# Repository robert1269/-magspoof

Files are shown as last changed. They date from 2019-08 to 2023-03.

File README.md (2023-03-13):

# MagSpoof V3 - Credit Card/Magstripe Spoofer

<a href="https://electroniccats.com/producto/magspoof-v3/">
  <p align="center">
  
  </p>
</a>

# How does MagSpoof work?

**MagSpoof V3** is a device that can spoof/emulate any magnetic stripe or credit card. It can work "wirelessly", even on **standard magstripe/credit card readers**, by generating a strong electromagnetic field that emulates a traditional magnetic stripe card.

* Allows you to store all of your credit cards and magstripes in one device
* Works on traditional magstripe readers **wirelessly** (no NFC/RFID required)
* Can **disable** Chip-and-PIN (code not included)
* Correctly **predicts** Amex credit card numbers + expirations from previous card number (code not included)
* Supports all three magnetic stripe tracks, and even supports Track 1+2 simultaneously
* Easy to build using Arduino or other common parts

MagSpoof can be used as a traditional credit card and simply store all of your credit cards (and with modification, can technically disable chip requirements) in various impressive and exciting form factors, or can be used for security research in any area that would traditionally require a magstripe, such as readers for credit cards, drivers licenses, hotel room keys, automated parking lot tickets, etc.

**Note:** MagSpoof does **not** enable you to use credit cards that you are not legally authorized to use. The Chip-and-PIN and Amex information is **not** implemented and using MagSpoof requires you to have/own the magstripes that you wish to emulate. Simply having a credit card number and expiration is not enough to perform transactions. MagSpoof **does** allow you to perform research in other areas of magstripes, microcontrollers, and electromagnetism, as well as learn about and create your own devices similar to other existing, commercial technologies such as <a href="http://www.samsung.com/us/support/answer/ANS00043865/997410383/">Samsung MST</a> and <a href="https://onlycoin.com/">Coin</a>.</p>

-----

# Based in work of Samy Kamkar

**Point of Contact:** [@SamyKamkar](https://twitter.com/samykamkar)

You can see more of my projects at <http://samy.pl> or contact me at <code@samy.pl>.

------

# Wiki and Getting Started 
**[Getting Started in our Wiki](https://github.com/ElectronicCats/magspoof/wiki)**

<p align="center">
  
</p>

------
# License
<a>
  
</a>
Electronic Cats invests time and resources in providing this open-source design. Please support Electronic Cats and open-source hardware by purchasing products from Electronic Cats!

Designed by Electronic Cats.

Firmware released under an GNU AGPL v3.0 license. See the LICENSE file for more information.

Hardware released under an CERN Open Hardware Licence v1.2. See the LICENSE_HARDWARE file for more information.

Electronic Cats is a registered trademark, please do not use if you sell these PCBs.

30 Octuber 2019

------

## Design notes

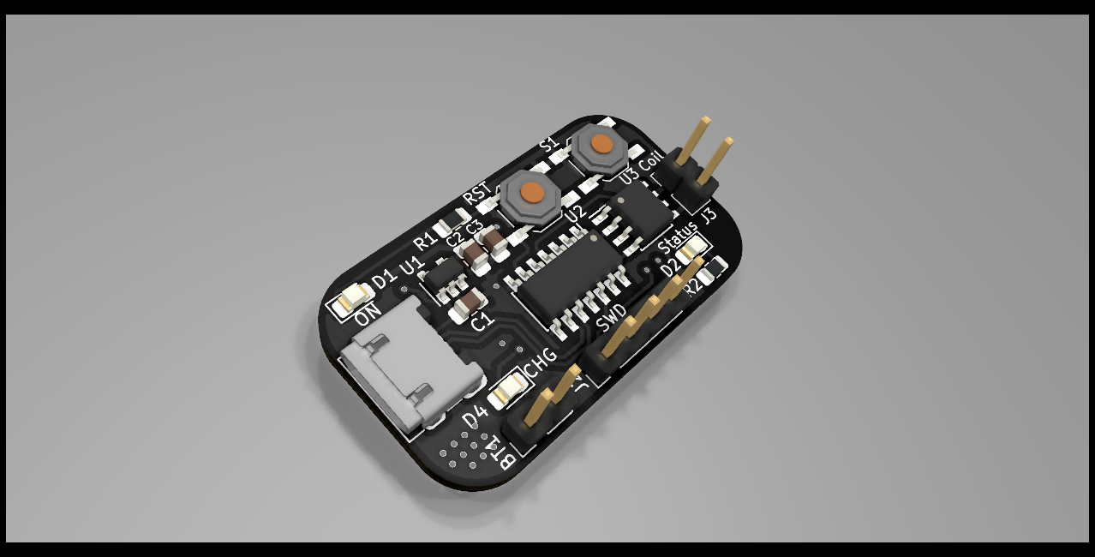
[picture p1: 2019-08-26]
V3/Hw/Magspoof_V3.png

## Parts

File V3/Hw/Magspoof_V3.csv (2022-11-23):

Item | Qty | Reference(s) | Value | manf#
1 | 1 | BT1 | Battery_Cell | -
2 | 4 | C1, C2, C4, C5 | 10uF | CL21A106KOQNNNG
3 | 1 | C3 | 0.1uF | CL21F104ZBCNNNC
4 | 1 | D1 | ON | 150080RS75000
5 | 1 | D2 | Status | 150080BS75000
6 | 1 | D3 | MBR120 | MBR120VLSFT3G
7 | 1 | D4 | CHG | 150080GS75000
8 | 1 | J1 | USB_B_Micro | 629105150521
9 | 1 | J2 | SWD | -
10 | 1 | J3 | Coil | -
11 | 2 | R1, R2 | 180R | RMCF0805JT180R
12 | 1 | R3 | 4.7K | RS-05K472JT
13 | 1 | R4 | 470 | CRCW0805470RFKEAC
14 | 1 | SW1 | RST | -
15 | 1 | SW2 | S1 | -
16 | 1 | U1 | AP2112K-3.3 | AP2112K-3.3
17 | 1 | U2 | ATSAMD11C14A | ATSAMD11C14A-SSUT
18 | 1 | U3 | TC4424 | TC4424AVOA713
19 | 1 | U4 | MCP73831 | MCP73831T-5ACI/OT

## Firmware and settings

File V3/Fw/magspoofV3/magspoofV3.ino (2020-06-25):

/************************************************************
  Magspoof V3
  Modified version by Salvador Mendoza (salmg.net)
  for Electronic Cats
  
  Original code by Samy Kamkar (http://samy.pl/magspoof/)
  
  This example demonstrates how to use Magspoof v3 by Electronic Cats
  https://github.com/ElectronicCats/magspoof
  
  Development environment specifics:
  IDE: Arduino 1.8.9
  Hardware Platform:
  Magspoof V3
  - SAMD11
  
  This code is beerware; if you see me (or any other Electronic Cats
  member) at the local, and you've found our code helpful,
  please buy us a round!
  Distributed as-is; no warranty is given.
*/

#define PIN_A 8
#define PIN_B 9
#define BUTTON_PIN 2
#define LED 14
#define CLOCK_US 500

#define BETWEEN_ZERO 53 // 53 zeros between track1 & 2

#define TRACKS 2


// consts get stored in flash as we don't adjust them
const char* tracks[] = {
"%B123456781234567^LASTNAME/FIRST^YYMMSSSDDDDDDDDDDDDDDDDDDDDDDDDD?\0", // Track 1
";123456781234567=112220100000000000000?\0" // Track 2
};

char revTrack[41];

const int sublen[] = {
  32, 48, 48 };
const int bitlen[] = {
  7, 5, 5 };

unsigned int curTrack = 0;
int dir;

void setup(){
  Serial.begin(9600);
  pinMode(LED, OUTPUT);
  pinMode(PIN_A, OUTPUT);
  pinMode(PIN_B, OUTPUT);
  pinMode(BUTTON_PIN, INPUT_PULLUP);

  storeRevTrack(2);
}

void blink(int pin, int msdelay, int times){
  for (int i = 0; i < times; i++){
    digitalWrite(pin, HIGH);
    delay(msdelay);
    digitalWrite(pin, LOW);
    delay(msdelay);
  }
}

// send a single bit out
void playBit(int sendBit){
  dir ^= 1;
  digitalWrite(PIN_A, dir);
  digitalWrite(PIN_B, !dir);
  delayMicroseconds(CLOCK_US);

  if (sendBit){
    dir ^= 1;
    digitalWrite(PIN_A, dir);
    digitalWrite(PIN_B, !dir);
  }
  delayMicroseconds(CLOCK_US);

}

// when reversing
void reverseTrack(int track){
  int i = 0;
  track--; // index 0
  dir = 0;

  while (revTrack[i++] != '\0');
  i--;
  while (i--)
    for (int j = bitlen[track]-1; j >= 0; j--)
      playBit((revTrack[i] >> j) & 1);
}

// plays out a full track, calculating CRCs and LRC
void playTrack(int track){
  int tmp, crc, lrc = 0;
  track--; // index 0
  dir = 0;

  // enable H-bridge and LED
  //digitalWrite(ENABLE_PIN, HIGH);

  // First put out a bunch of leading zeros.
  for (int i = 0; i < 25; i++)
    playBit(0);

  //
  for (int i = 0; tracks[track][i] != '\0'; i++)
  {
    crc = 1;
    tmp = tracks[track][i] - sublen[track];

    for (int j = 0; j < bitlen[track]-1; j++)
    {
      crc ^= tmp & 1;
      lrc ^= (tmp & 1) << j;
      playBit(tmp & 1);
      tmp >>= 1;
    }
    playBit(crc);
  }

  // finish calculating and send last "byte" (LRC)
  tmp = lrc;
  crc = 1;
  for (int j = 0; j < bitlen[track]-1; j++)
  {
    crc ^= tmp & 1;
    playBit(tmp & 1);
    tmp >>= 1;
  }
  playBit(crc);

  // if track 1, play 2nd track in reverse (like swiping back?)
  if (track == 0)
  {
    // if track 1, also play track 2 in reverse
    // zeros in between
    for (int i = 0; i < BETWEEN_ZERO; i++)
      playBit(0);

    // send second track in reverse
    reverseTrack(2);
  }

  // finish with 0's
  for (int i = 0; i < 5 * 5; i++)
    playBit(0);

  digitalWrite(PIN_A, LOW);
  digitalWrite(PIN_B, LOW);
}

// stores track for reverse usage later
void storeRevTrack(int track){
  int i, tmp, crc, lrc = 0;
  track--; // index 0
  dir = 0;

  for (i = 0; tracks[track][i] != '\0'; i++)
  {
    crc = 1;
    tmp = tracks[track][i] - sublen[track];

    for (int j = 0; j < bitlen[track]-1; j++)
    {
      crc ^= tmp & 1;
      lrc ^= (tmp & 1) << j;
      tmp & 1 ?
        (revTrack[i] |= 1 << j) :
        (revTrack[i] &= ~(1 << j));
      tmp >>= 1;
    }
    crc ?
      (revTrack[i] |= 1 << 4) :
      (revTrack[i] &= ~(1 << 4));
  }

  // finish calculating and send last "byte" (LRC)
  tmp = lrc;
  crc = 1;
  for (int j = 0; j < bitlen[track]-1; j++)
  {
    crc ^= tmp & 1;
    tmp & 1 ?
      (revTrack[i] |= 1 << j) :
      (revTrack[i] &= ~(1 << j));
    tmp >>= 1;
  }
  crc ?
    (revTrack[i] |= 1 << 4) :
    (revTrack[i] &= ~(1 << 4));

  i++;
  revTrack[i] = '\0';
}

void loop(){
    if (digitalRead(BUTTON_PIN) == 0){
    Serial.println("Activating MagSpoof...");
    playTrack(1 + (curTrack++ % 2));
    
    digitalWrite(LED,HIGH);
    delay(200);
    digitalWrite(LED,LOW);
    delay(200);
  
  }
}

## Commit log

2019-08-21 Add preliminar schematic
    [Magspoof_V2.kicad_pcb, Magspoof_V2.sch]
2019-08-26 Add foortprints and first route
    [Magspoof_V2.sch]
2019-10-29 Update desing
    [Magspoof_V2.kicad_pcb, Magspoof_V2.sch]
2019-10-29 change version name
    [Magspoof_V3.kicad_pcb, Magspoof_V3.sch]
2019-10-29 Add magspoof v1
    [MagSpoofTC.csv, MagSpoofTC.kicad_pcb, MagSpoofTC.sch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]
2019-10-29 Change folders name
    [MagSpoofTC.csv, MagSpoofTC.kicad_pcb, MagSpoofTC.sch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]
2019-10-29 add manf#
    [Magspoof_V3.sch]
2019-12-24 Update instructions for install in arduino
2020-02-04 fix diode
    [Magspoof_V3.kicad_pcb]
2022-11-23 Changed charge resistance to 4.7K and updated BOM
    [Magspoof_V3.csv, Magspoof_V3.kicad_sch]
2023-02-28 Footprint Update
    The foot print of the V3 of the Magspoof was update.
    [Magspoof_V3 (2).kicad_pcb]
